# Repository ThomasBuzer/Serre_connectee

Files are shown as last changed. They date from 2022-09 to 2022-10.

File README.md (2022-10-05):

# Serre_connectee

## installation de la carte ESP32 dans l'IDE et librairies à installer

1 installer les cartes ESP32 [ici](https://www.upesy.fr/blogs/tutorials/install-esp32-on-arduino-ide-complete-guide)

La carte est L'"AI Thinker ESP32-CAM"
Les paramètrs sont ceux par défaut.

2 librairies

Pour installer les librairies, aller dans **Outils** > **Gérer les bibliothèques**
Attention, la vesrison de la bibliothèque peut avoir une incidence sur le fonctionnement (on peut sélectionner la version à l'installation.

les librairies à installer sont les deux premières sur la photo suivante (avec les versions !) :

<div align="center">
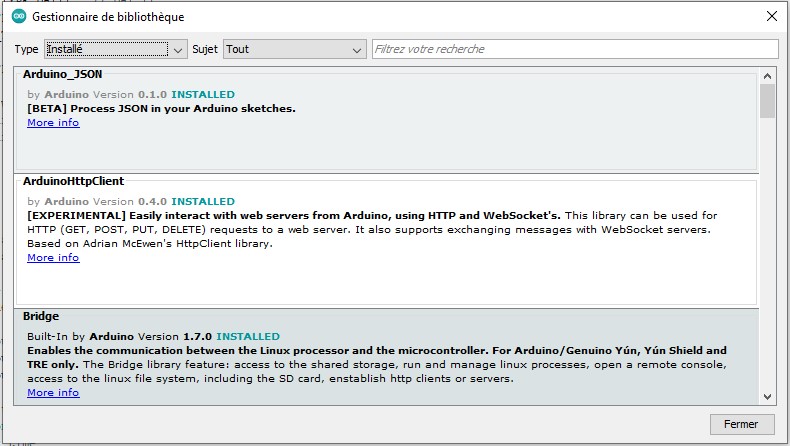
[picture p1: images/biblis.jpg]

</div>

## Flash un nouveau programme 

**Débrancher l'alimentation** de la carte.

Utiliser le convertisseur USB to TTL : 
- GND -> GND
- RXD -> U0T
- TXD -> U0R

utiliser un **jumper** pour connecter IO0 et GND sur l'ESP32.

<div align="center">
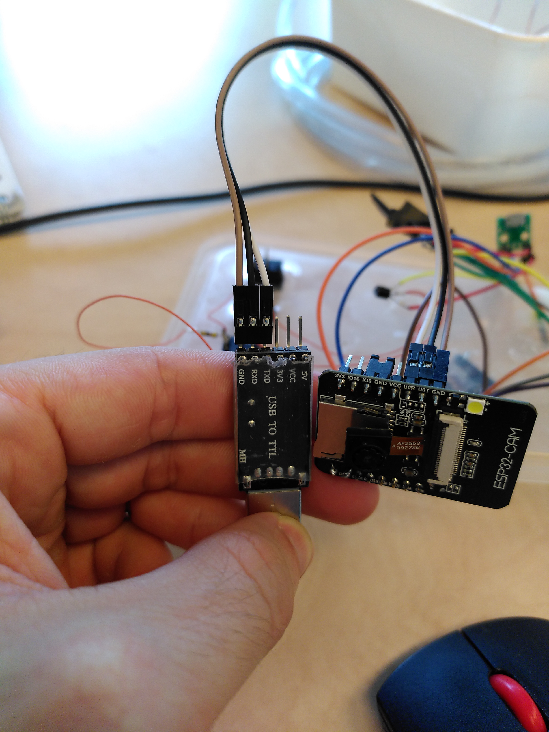
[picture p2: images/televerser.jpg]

</div>

Brancher l'**USB** au PC

Connecter l'**alimentation** de l'ESP32.

**Téléverser le programme sur l'ESP32 avec l'IDE arduino**

**Enlever le jumper** entre IO0 et GND

Débrancher l'alimentation et la rebrancher.

## Programmes

Le programme a utiliser / modifier pour l'ESP32 est le "final_version.ino". Il est sectionné en plusieurs fichiers contenant les différentes sous fonctions.

Le fichier (codes.gs)[code.gs] est le code google script qui communique avec l'ESP pour remplir le ggsheet et enregistrer les images. Ce script doit être déployer et le code de déploiement (AKfycbx-9i9Zu6WyBMAfQey_Hle-L-dqW94WVCNc_f8sVzF-vi08NC7xyscnGzp_XL6DOj6w par exemple) doit être insérer dans le programme .ino dans le fichier global_variables.

## liste des inspirations

sauvegarde des images dans ggdrive
https://github.com/gsampallo/esp32cam-gdrive

lire le spreadsheet
https://www.youtube.com/watch?v=0LoeaewIAdY

avoir l'heure depuis l'internet
https://randomnerdtutorials.com/esp32-date-time-ntp-client-server-arduino/

requêtes internet de base
https://randomnerdtutorials.com/esp32-http-get-post-arduino/#http-post

sleepmode
https://www.mischianti.org/2021/03/10/esp32-power-saving-modem-and-light-sleep-2/

## Améliorations directement possibles par ordre de difficulté

- changer les fils du ventilateur et de la pompe pour des fils plus gros et peut-être plus étanches
- changer les transistors npn pour des transistors NMOS : ça consomme moins
- ajouter un ads1115 pour la mesure de luminosité et d'autres ? (c'est compliqué parce que les pins de base sur l'ESP sont déjà pris)

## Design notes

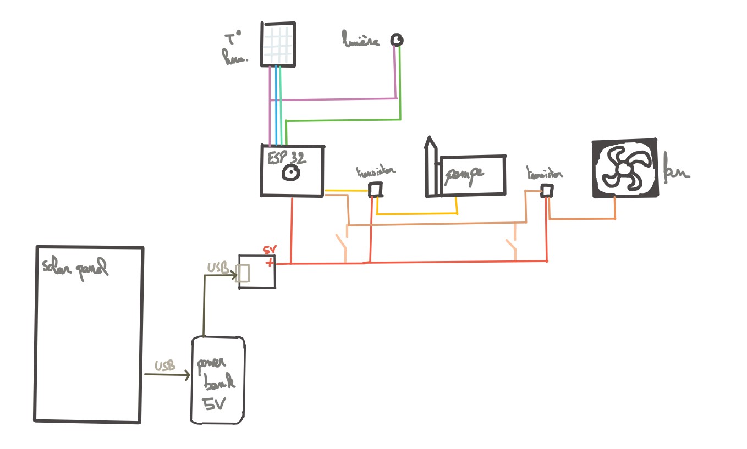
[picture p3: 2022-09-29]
images/schéma.jpg

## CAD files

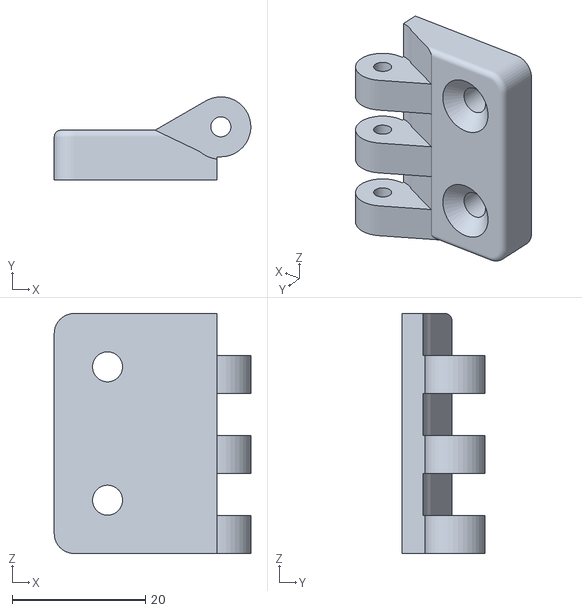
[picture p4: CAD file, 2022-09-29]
Inventor/hinge.STL
29.5 x 12.5 x 36.0

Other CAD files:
Inventor/Imported Components/hinge/hinge.ipt
Inventor/OldVersions/bois.0002.ipt
Inventor/OldVersions/capot.0002.ipt
Inventor/OldVersions/electronics.0001.iam
Inventor/OldVersions/hinge.0002.iam
Inventor/OldVersions/poigne.0001.ipt
Inventor/OldVersions/serre.0005.iam
Inventor/OldVersions/solar_panel.0002.ipt
Inventor/bois.ipt
Inventor/capot.ipt
Inventor/dht11.ipt
Inventor/electronics.iam
Inventor/halfhinge.ipt
Inventor/hinge.iam
Inventor/plafond.ipt
Inventor/poigne.ipt
Inventor/serre.iam
Inventor/solar_panel.ipt

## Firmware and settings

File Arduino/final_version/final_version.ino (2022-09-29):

// Load Wi-Fi library
#include <WiFi.h>

#include "soc/soc.h"
#include "soc/rtc_cntl_reg.h"
#include "DHT.h"
#include <HTTPClient.h>
#include "time.h"
#include "fonctions.h"

#define DHTTYPE DHT11   // DHT 11
#define DHTPIN dhtPin     // Digital pin connected to the DHT sensor
#define uS_TO_S_FACTOR 1000000ULL

DHT dht(DHTPIN, DHTTYPE); // setup the sensor

// Replace with your network credentials
//const char* ssid = "NETGEAR95";
//const char* password = "aquaticpiano858";

const char* ssid = "FP3";
const char* password = "bmx0070B";


// Set web server port number to 80
WiFiServer server(80);

// Variable to store the HTTP request
String header;

// Assign output variables to GPIO pins
const int output26 = 33;
const int output27 = 4;

// Current time
unsigned long currentTime = millis();
// Previous time
unsigned long previousTime = 0; 
// Define timeout time in milliseconds (example: 2000ms = 2s)
const long timeoutTime = 2000;


//Set NTP Request Parameters
const char* ntpServer = "pool.ntp.org";
const long  gmtOffset_sec = 3600;
const int   daylightOffset_sec = 3600;

bool wattered = false;
bool fanState = false;
bool overTemp = false;
bool overHumid = false;

int compteurTimelapse = 0;

void setModemSleep() {
    WiFi.setSleep(true);
    if (!setCpuFrequencyMhz(40)){
        Serial2.println("Not valid frequency!");
    }
    // Use this if 40Mhz is not supported
    // setCpuFrequencyMhz(80);
}
 
void wakeModemSleep() {
    setCpuFrequencyMhz(240);
}

void setup() {
  WRITE_PERI_REG(RTC_CNTL_BROWN_OUT_REG, 0);

  Serial.begin(115200);
  // Initialize the output variables as outputs
  pinMode(output26, OUTPUT);
  pinMode(output27, OUTPUT);
  // Set outputs to LOW
  digitalWrite(output26, HIGH);
  digitalWrite(output27, LOW);

  // Connect to Wi-Fi network with SSID and password
  Serial.print("Connecting to ");
  Serial.println(ssid);
    
  int timeout = 30;
  WiFi.begin(ssid, password);
  while (WiFi.status() != WL_CONNECTED) {
    delay(1000);
    Serial.print(".");
    timeout -= 1;
    if(timeout == 0){
      Serial.println("Time out connection wifi");
      ESP.restart();
    }
  }
  // Print local IP address and start web server
  Serial.println("");
  Serial.println("WiFi connected.");
  Serial.println("IP address: ");
  Serial.println(WiFi.localIP());
  server.begin();

  
  configTime(gmtOffset_sec, daylightOffset_sec, ntpServer);

  //Setup initial states of pump and fan
  pinMode(fanPin, OUTPUT);
  pinMode(pumpPin, OUTPUT);
  digitalWrite(fanPin, LOW);
  digitalWrite(pumpPin, LOW);

  //setup sensor power pin
  pinMode(sensorPower, OUTPUT);
  digitalWrite(sensorPower, HIGH);
  delay(100);
  dht.begin();

  //setup camera
  setupCam();

}

void loop(){
  
  //GET sensors information
  float temp = dht.readTemperature();
  float humidity = dht.readHumidity();
  int light = analogRead(lightPin);

  //Update all the parameters
  updateParameters();

  //log the data
  sendVariables( temp, humidity, float(light));

  //check arrosage automatique
  int currentHour = getHour();
  if(currentHour == HEURE_AROSAGE and !wattered and ARROSAGE_AUTOMATIQUE == 1){
      Serial.println("Début de l'arosage pour ce temps :");
      Serial.println(DUREE_AROSAGE);
      
      digitalWrite(pumpPin, HIGH);
      delay(1000 * DUREE_AROSAGE);
      digitalWrite(pumpPin, LOW);
  
      Serial.println("Arosage terminé");
      wattered = true;
   }
   if(currentHour == 1 and wattered)wattered = false;
  
  //update pump status with force_pompe
  digitalWrite(pumpPin, FORCE_POMPE);

  //update LED state
  digitalWrite(whiteLed, LED);

  //update fan state
  switch(fanState){
    case true:
      if(overTemp && temp <= MIN_TEMP)overTemp = false;
      if(overHumid && humidity <= MIN_HUMIDITY)overHumid = false;
      break;
    case false:
      if(temp >= MAX_TEMP)overTemp = true;
      if(humidity >= MAX_HUMIDITY)overHumid = true;
      break;
  }
  fanState = overHumid || overTemp;
  digitalWrite(fanPin, fanState);

  //capture image
  if(TIMELAPSE == 1)compteurTimelapse++;
  if( (TIMELAPSE == 1 && compteurTimelapse >= FREQUENCE_TIMELAPSE) || FORCE_PHOTO == 1){
    Serial.println("Capturing Photo");
    saveCapturedImage();
    compteurTimelapse = 0;
  }
  
  //delay(DUREE_DEEPSLEEP*1000);
  //Setup sleep
  esp_sleep_enable_timer_wakeup(DUREE_DEEPSLEEP * uS_TO_S_FACTOR);
  delay(100);
  //esp_light_sleep_start();
  setModemSleep();
  delay(DUREE_DEEPSLEEP * 1000);
  wakeModemSleep();
  delay(3000);
  
}

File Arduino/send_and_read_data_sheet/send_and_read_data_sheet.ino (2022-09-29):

// Load Wi-Fi library
#include <WiFi.h>
#include "soc/soc.h"
#include "soc/rtc_cntl_reg.h"
#include "DHT.h"
#include <HTTPClient.h>
#include "time.h"
#include <Arduino_JSON.h>

#define DHTTYPE DHT11   // DHT 11
#define DHTPIN 12     // Digital pin connected to the DHT sensor

DHT dht(DHTPIN, DHTTYPE); // setup the sensor

// Replace with your network credentials
const char* ssid = "NETGEAR95";
const char* password = "aquaticpiano858";

// Set web server port number to 80
WiFiServer server(80);

// Variable to store the HTTP request
String header;

// Auxiliar variables to store the current output state
String output26State = "off";
String output27State = "off";

// Assign output variables to GPIO pins
const int output26 = 33;
const int output27 = 4;

// Current time
unsigned long currentTime = millis();
// Previous time
unsigned long previousTime = 0; 
// Define timeout time in milliseconds (example: 2000ms = 2s)
const long timeoutTime = 2000;


//Set NTP Request Parameters
const char* ntpServer = "pool.ntp.org";
const long  gmtOffset_sec = 3600;
const int   daylightOffset_sec = 3600;

String GOOGLE_SCRIPT_ID = "AKfycbwz7PGT_d0WqjZNljvVgTL-JOlp5CIQEWr-2hi93QzqW-zDg0fm_YS07wq9Yspp5LDX";    // change Gscript ID

String printLocalTime()
{
  struct tm timeinfo;
  if(!getLocalTime(&timeinfo)){
    Serial.println("Failed to obtain time");
    return "None";
  }
  //Serial.println(&timeinfo, "%A, %B %d %Y %H:%M:%S");
  char timeWeekDay[200];
  strftime(timeWeekDay,200, "%B %d %Y %H:%M:%S", &timeinfo);
  return timeWeekDay;
}


void setup() {
  WRITE_PERI_REG(RTC_CNTL_BROWN_OUT_REG, 0);

  Serial.begin(115200);
  // Initialize the output variables as outputs
  pinMode(output26, OUTPUT);
  pinMode(output27, OUTPUT);
  // Set outputs to LOW
  digitalWrite(output26, LOW);
  digitalWrite(output27, LOW);

  // Connect to Wi-Fi network with SSID and password
  Serial.print("Connecting to ");
  Serial.println(ssid);
  WiFi.begin(ssid, password);
  while (WiFi.status() != WL_CONNECTED) {
    delay(500);
    Serial.print(".");
  }
  // Print local IP address and start web server
  Serial.println("");
  Serial.println("WiFi connected.");
  Serial.println("IP address: ");
  Serial.println(WiFi.localIP());
  server.begin();

  dht.begin();
  configTime(gmtOffset_sec, daylightOffset_sec, ntpServer);

}

void loop(){
  float temp = dht.readTemperature();
  float humidity = dht.readHumidity();
  float light = analogRead(13);

  
  String timestamp = printLocalTime();
  Serial.println(timestamp);
  delay(1000);
  WiFiClient client = server.available();   // Listen for incoming clients

  if (client) {                             // If a new client connects,
    currentTime = millis();
    previousTime = currentTime;
    Serial.println("New Client.");          // print a message out in the serial port
    String currentLine = "";                // make a String to hold incoming data from the client
    while (client.connected() && currentTime - previousTime <= timeoutTime) {  // loop while the client's connected
      currentTime = millis();
      if (client.available()) {             // if there's bytes to read from the client,
        char c = client.read();             // read a byte, then
        Serial.write(c);                    // print it out the serial monitor
        header += c;
        if (c == '\n') {                    // if the byte is a newline character
          // if the current line is blank, you got two newline characters in a row.
          // that's the end of the client HTTP request, so send a response:
          if (currentLine.length() == 0) {
            // HTTP headers always start with a response code (e.g. HTTP/1.1 200 OK)
            // and a content-type so the client knows what's coming, then a blank line:
            client.println("HTTP/1.1 200 OK");
            client.println("Content-type:text/html");
            client.println("Connection: close");
            client.println();
            
            // turns the GPIOs on and off
            if (header.indexOf("GET /26/on") >= 0) {
              Serial.println("GPIO 26 on");
              output26State = "on";
              digitalWrite(output26, HIGH);
            } else if (header.indexOf("GET /26/off") >= 0) {
              Serial.println("GPIO 26 off");
              output26State = "off";
              digitalWrite(output26, LOW);
            } else if (header.indexOf("GET /read") >= 0) {
              String serverName = "https://script.google.com/macros/s/"+GOOGLE_SCRIPT_ID+"/exec?read=1";
              
              HTTPClient http;
              http.setFollowRedirects(HTTPC_STRICT_FOLLOW_REDIRECTS);
              http.begin(serverName);
              int httpCode = http.GET();
              Serial.print("HTTP Status Code: ");
              Serial.println(httpCode);
              //---------------------------------------------------------------------
              //getting response from google sheet
              String payload = {};
              if (httpCode > 0) {
                  payload = http.getString();
                  Serial.println("Payload: "+payload);    
              }
              //---------------------------------------------------------------------
              http.end();

              //TREAT THE PAYLOAD

              JSONVar myObject = JSON.parse(payload);
              // JSON.typeof(jsonVar) can be used to get the type of the var
              if (JSON.typeof(myObject) == "undefined") {
                Serial.println("Parsing input failed!");
                return;
              }
              
              Serial.print("JSON object = ");
              Serial.println(myObject);
              
              // myObject.keys() can be used to get an array of all the keys in the object
              JSONVar keys = myObject.keys();
              double sensorReadingsArr = 0;
              for (int i = 0; i < keys.length(); i++) {
                JSONVar value = myObject[keys[i]];
                Serial.print(keys[i]);
                Serial.print(" = ");
                Serial.println(value);
                sensorReadingsArr = double(value);
              }
              digitalWrite(output27, bool(sensorReadingsArr));
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
